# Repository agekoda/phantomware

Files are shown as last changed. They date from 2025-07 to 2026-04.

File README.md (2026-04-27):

<div align="center">

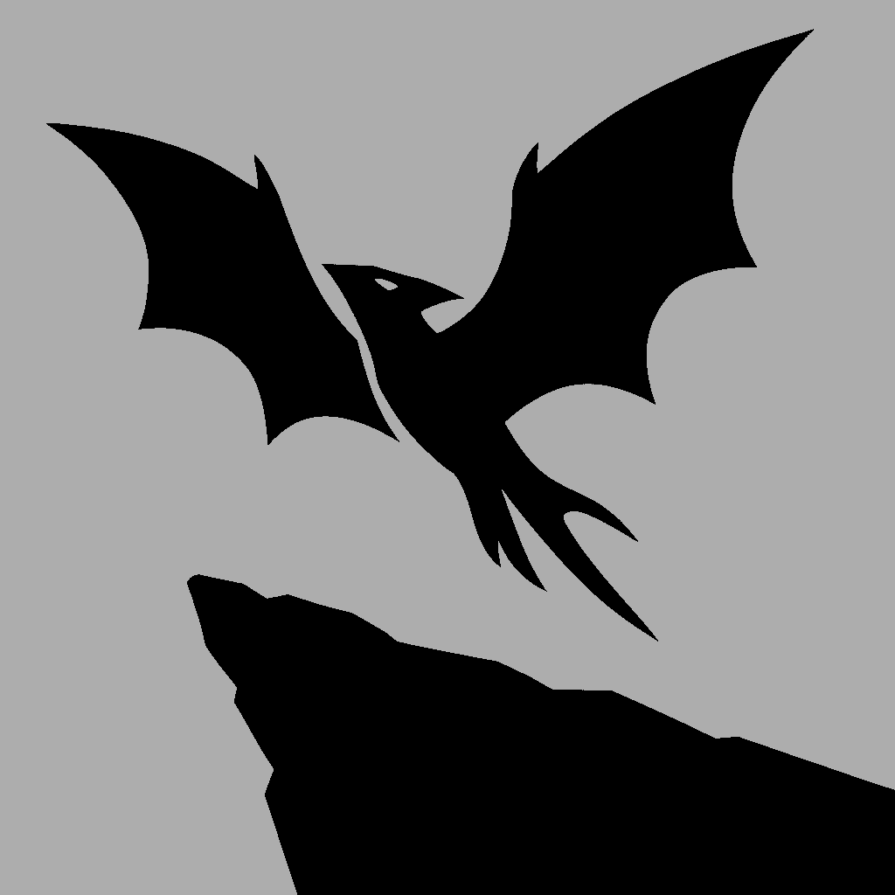
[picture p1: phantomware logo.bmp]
  
  
  <h1> phantomware </h1>
  <p> Compact, powerful ESP32-S3 platform for IR, NFC, sensors, WiFi & more. </p>

<!-- Badges -->





<h4>
  <a href="https://www.tiktok.com/@designedbykoda">
    
  </a>

  <a href="https://www.youtube.com/@zdhd">
    
  </a>

  <a href="https://designedbykoda.com">
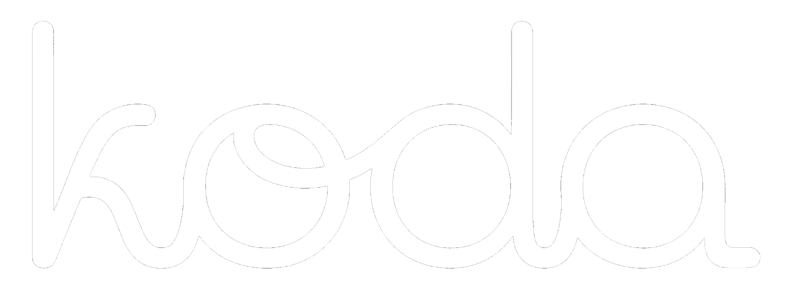
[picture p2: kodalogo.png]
    
  </a>
</h4>
</div>

## 🔥 Overview

Phantomware is a fully custom-built multi-tool device based on the ESP32-S3, designed for wireless analysis, signal interaction, and hardware experimentation.

It combines RF, GPIO, IR, and NFC capabilities into a portable platform featuring a 240×320 TFT display, SD card storage, and a 3000mAh battery system with a full charging circuit, MAX17055 fuel gauge, and built-in overcharge and overcurrent protection.

With 6 navigation buttons and a modular software framework, Phantomware is built for advanced IoT development, prototyping, and hardware exploration.

<div align="center"> 
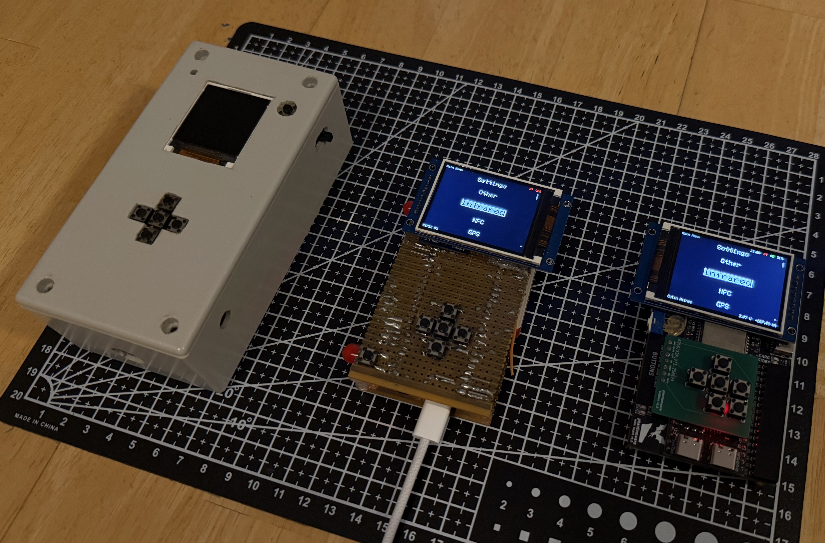
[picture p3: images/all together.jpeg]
  
</div>

<div>&nbsp;</div>

## Phantomware vs. Flipper Zero

| Feature | Phantomware | Flipper Zero |
|---|---|---|
| Microcontroller | ESP32-S3 Dual-core Xtensa LX7 | STM32WB55RG |
| Bluetooth and WiFi? | Bluetooth 5 & WiFi 4 | Bluetooth 5.4 |
| Display | 2" 240x320 TFT LCD | 1.4" 128x64 Monochrome |
| IR Transceiver | 3x VSMY14940 LEDs + TSOP75348WTR | 3x VSMY14940 + TSOP75338TR |
| NFC Support | PN532 via SPI | ST25R3916 |
| Battery & Power Mgmt | 3000mAh LiPo + TP4056 + MAX17055 | 2100mAh + BQ25896 + BQ27220 |
| Expansion Options | Micro SD + 16 GPIOs | Micro SD + 18 GPIOs |
| Target Use Case | Signal analysis, RFID/NFC, IR, tinkering | Sub-GHz, RFID/NFC, IR, utility |
| Open Source? | Open Source & fully customisable | Open Source with limitations |
| Typical Price Point | ~$50 USD | ~$200 USD |

> [!NOTE]
> Information for Flipper Zero is based on publicly available specifications and may vary.

## 🚀 Features

### 🔌 GPIO Toolkit

* PWM signal generator
* Oscilloscope
* Frequency analyser
* Voltmeter
* Resistor calculator
* USB to UART bridge

### 📡 WiFi Tools *(educational use only)*

* Network scan
* Packet monitor
* Spectrum waterfall
* Deauthentication Attack
* Beacon spam
* Evil portal / Captive portal
* Access point hosting
* Connect to AP and host HTML

### 📶 Bluetooth Tools

* BLE scanning
* Device advertisement spam (Apple / Samsung / Windows)

### ⌨️ HID Tools

* BadUSB
* BadBT (Bluetooth HID attacks)

### 💬 Communication

* ESP-NOW messaging
* NRF24-based chat system

### 🧩 Expansion Support

* GPS modules
* PN532 NFC module
* Future GPIO-based add-ons

<!-- nRFBOX V2 -->
## 📸 Versions

<table>
  <tr>
    <td style="text-align: center;">
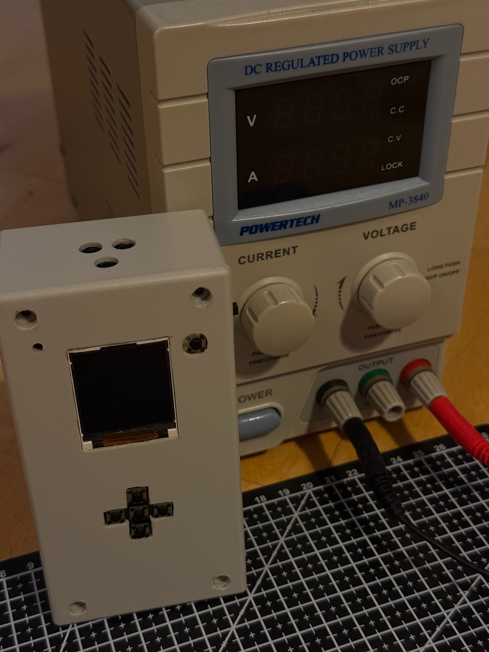
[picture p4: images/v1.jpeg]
phantomware v1
      
      <p style="font-style: italic; font-size: 14px; margin-top: 5px;">v1 prototype based on ESP32</p>
    </td>    
    <td style="text-align: center;">
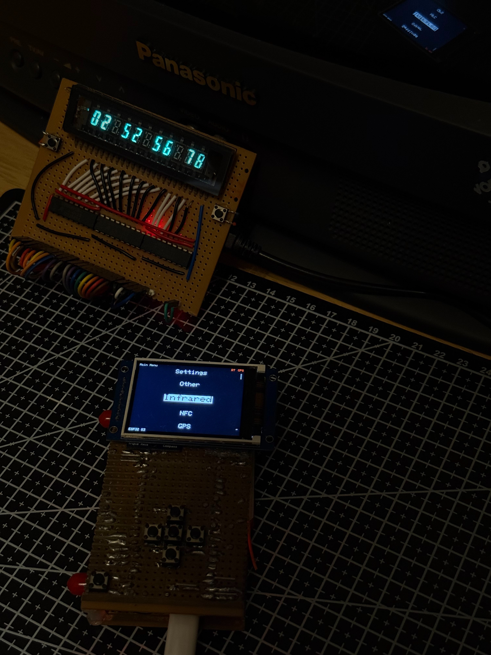
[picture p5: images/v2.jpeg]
phantomware v2
      
      <p style="font-style: italic; font-size: 14px; margin-top: 5px;">v2 based on ESP32-S3</p>
    </td>
    </td>    
    <td style="text-align: center;">
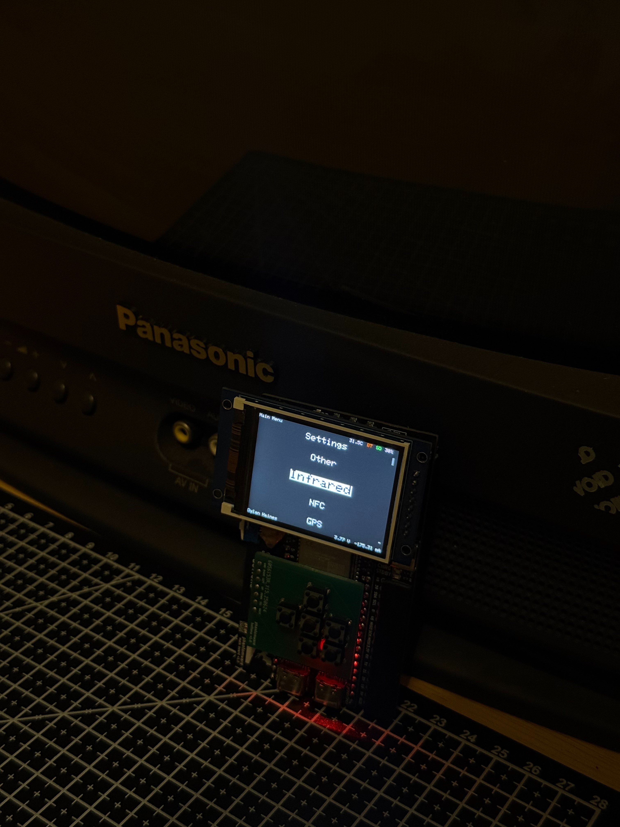
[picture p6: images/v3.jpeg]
phantomware v3
      
      <p style="font-style: italic; font-size: 14px; margin-top: 5px;">v3 based on ESP32-S3 with PCBA and battery</p>
    </td>
  </tr>
</table>

## 🚨 Disclaimer

This project is intended for **educational and research purposes only**.

Do not use this device to interfere with networks, devices, or signals that you do not own or have explicit permission to test. Misuse may violate local laws and regulations.

<!-- License -->
## ⚠️ License

Distributed under the MIT License. See LICENSE.txt for more information.

<!-- Contact -->
## 🤝 Contact

Email - enquiries@designedbykoda.com

Project Link: [https://github.com/agekoda/phantomware](https://github.com/agekoda/phantomware)

<div>&nbsp;</div>

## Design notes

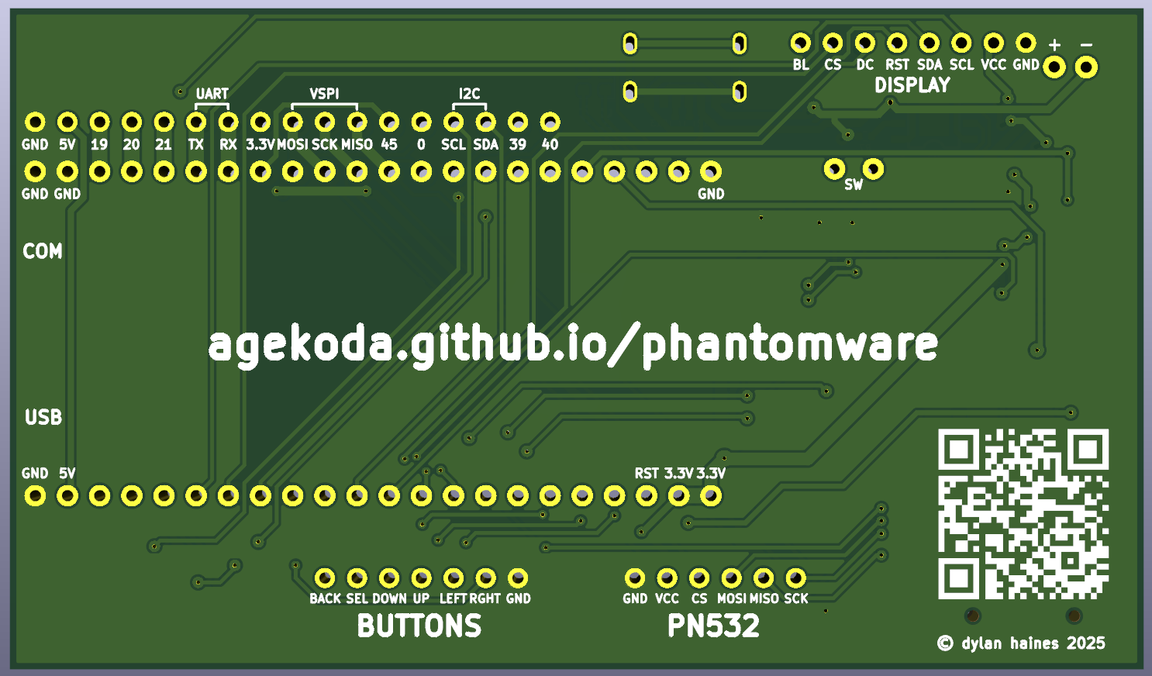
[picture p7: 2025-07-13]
images/back.png

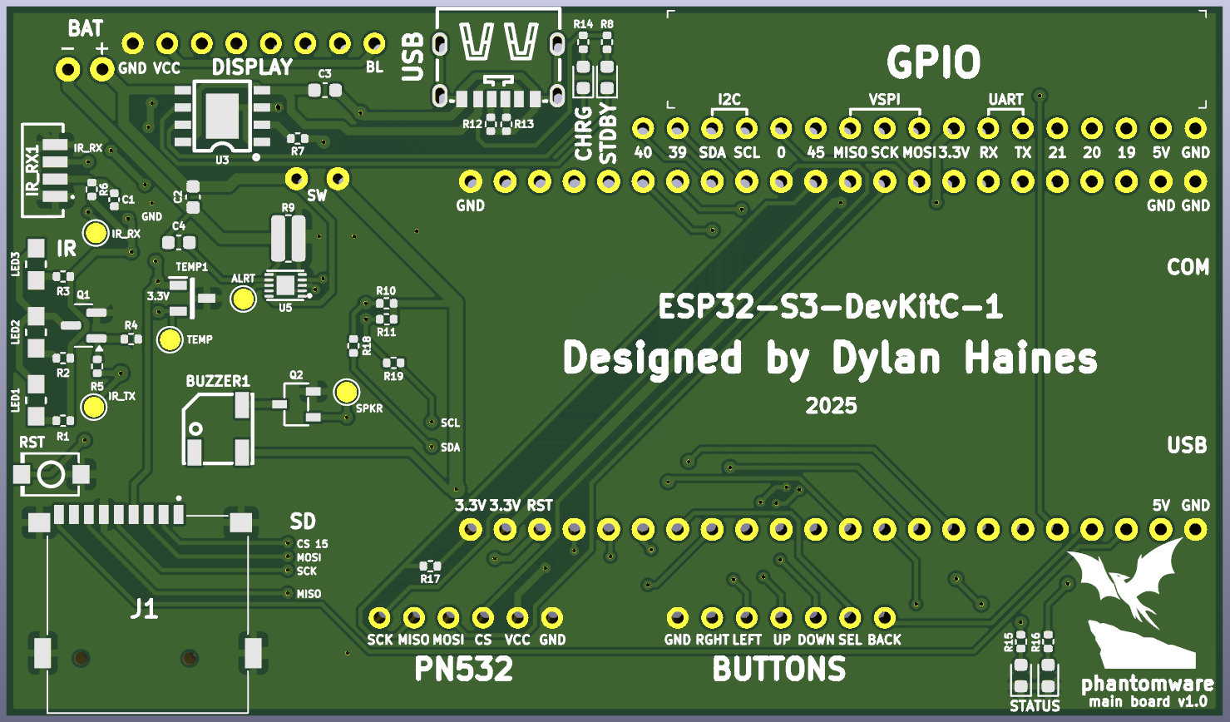
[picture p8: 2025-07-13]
images/front.png

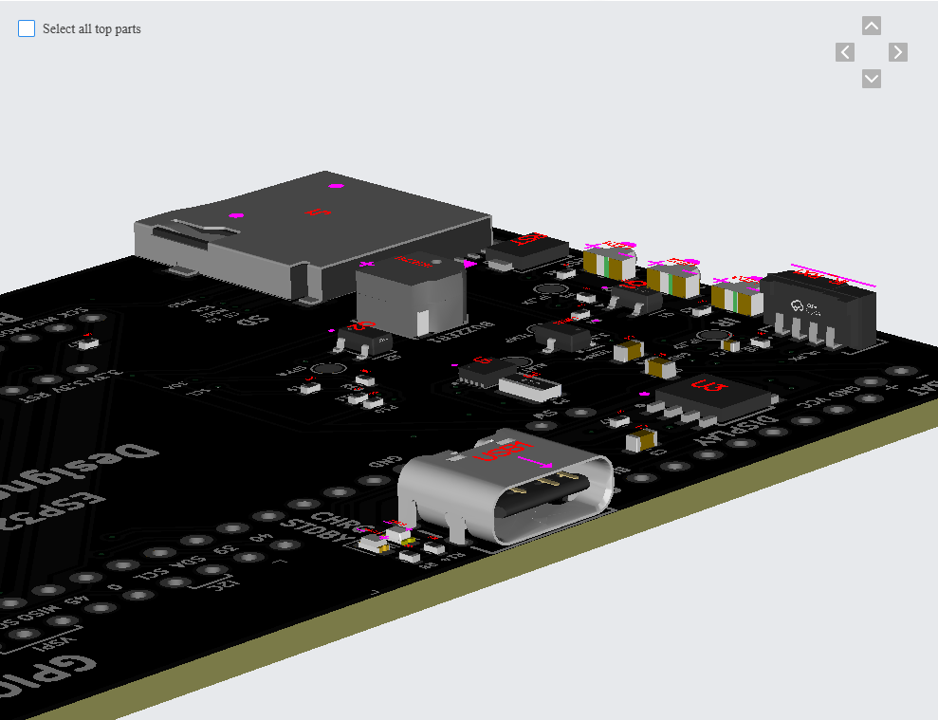
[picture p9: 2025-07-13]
images/3d 3.png

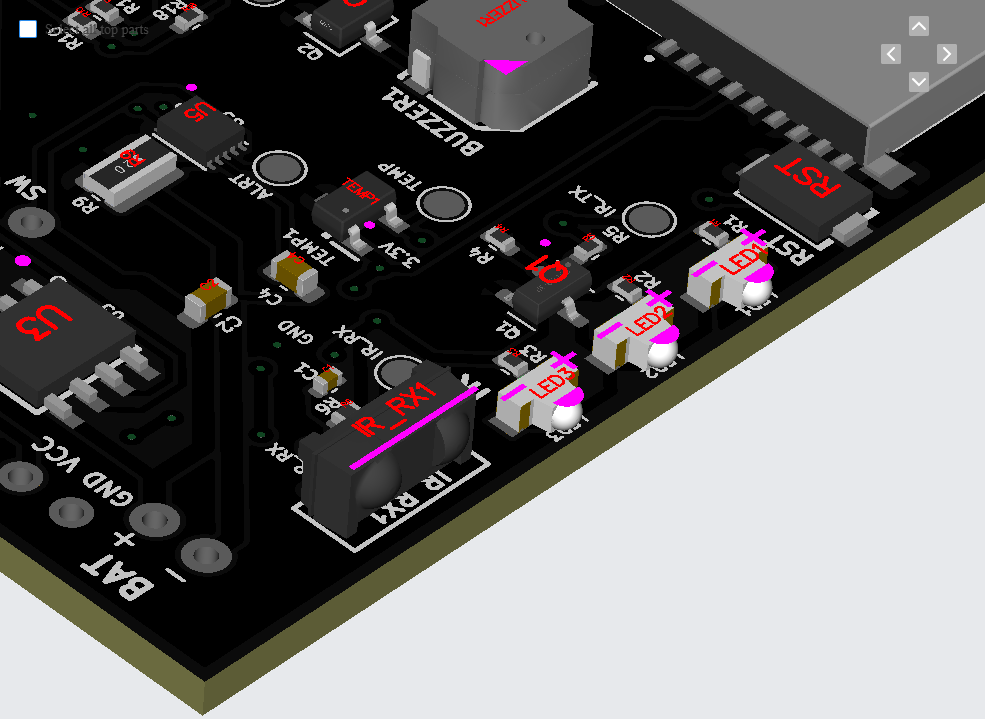
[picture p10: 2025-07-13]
images/3d 1.png

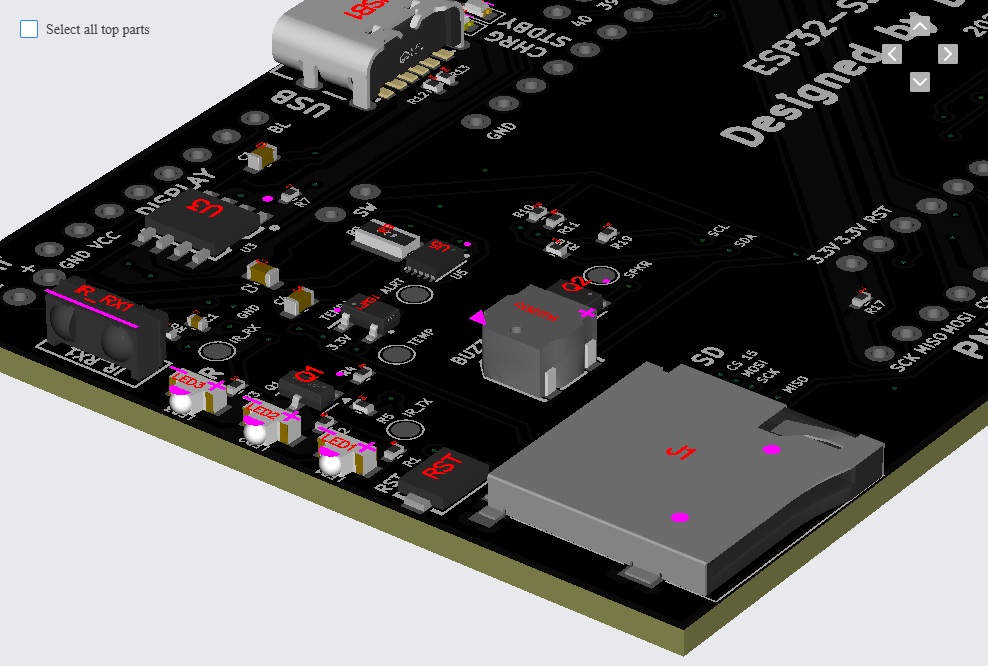
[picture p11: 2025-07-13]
images/3d 2.png

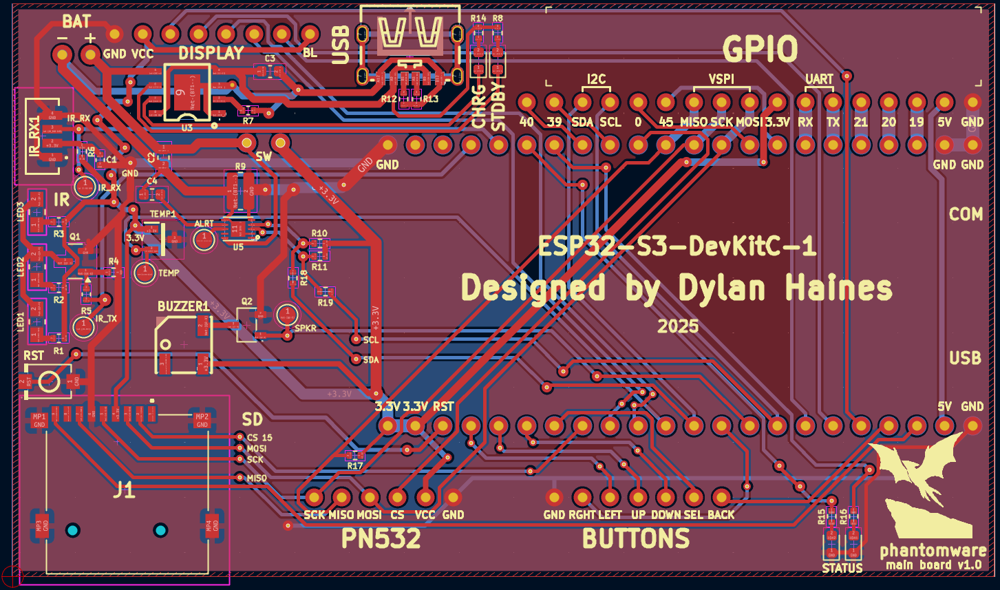
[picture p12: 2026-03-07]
images/pcb.png

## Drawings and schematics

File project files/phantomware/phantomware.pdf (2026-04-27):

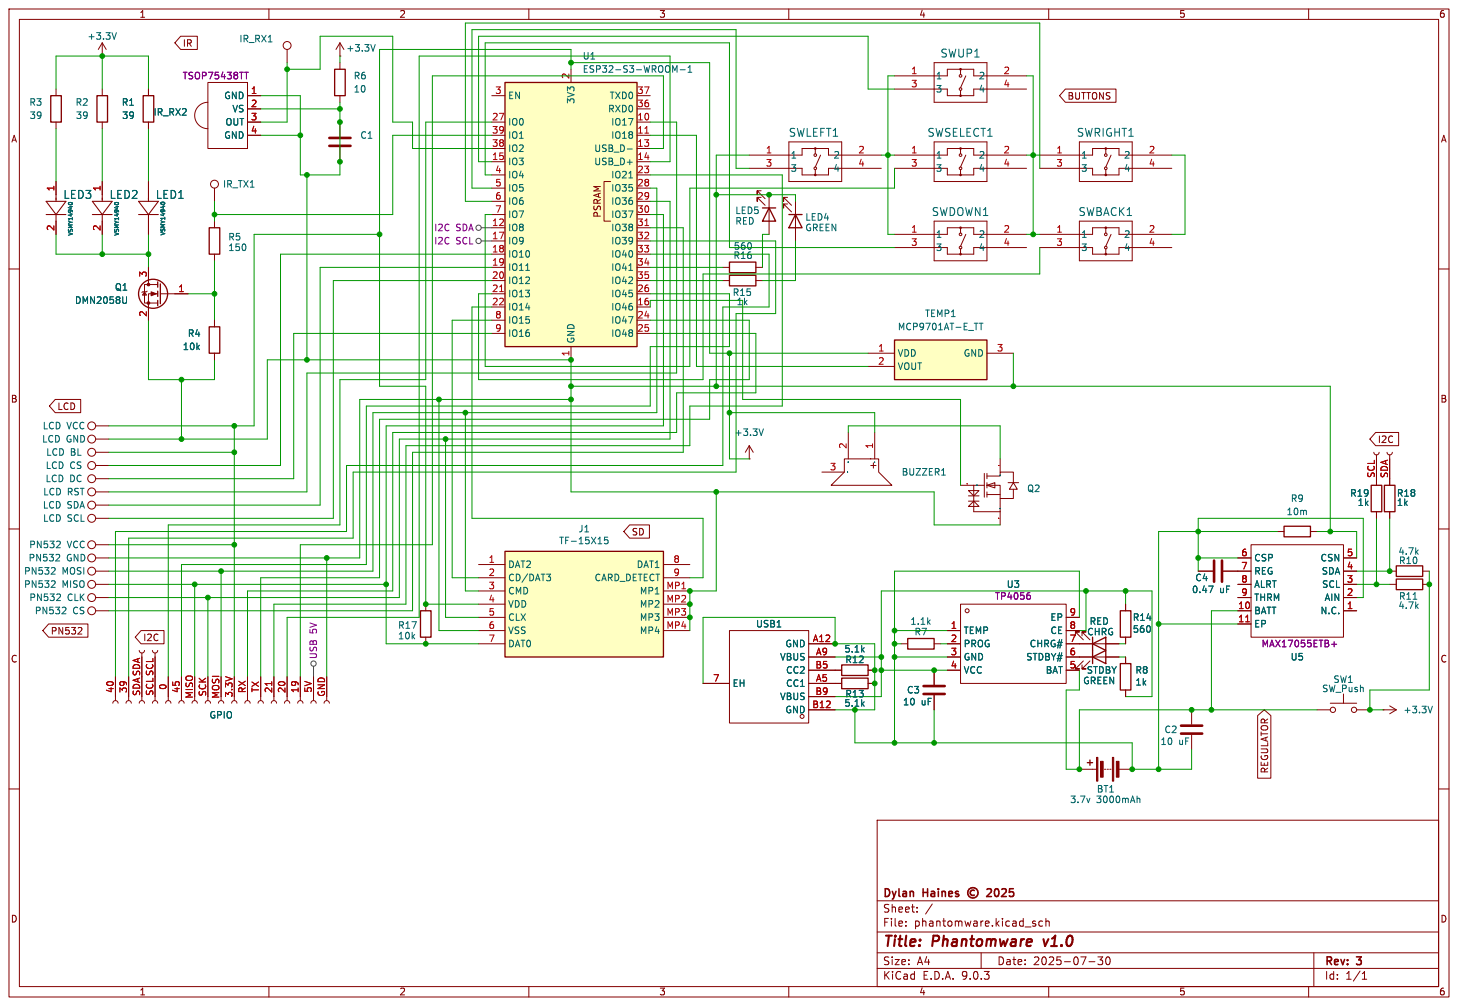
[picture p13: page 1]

IR_RX2TSOP75438TT GND 1 VS 2 OUT 3 GND 4 R1

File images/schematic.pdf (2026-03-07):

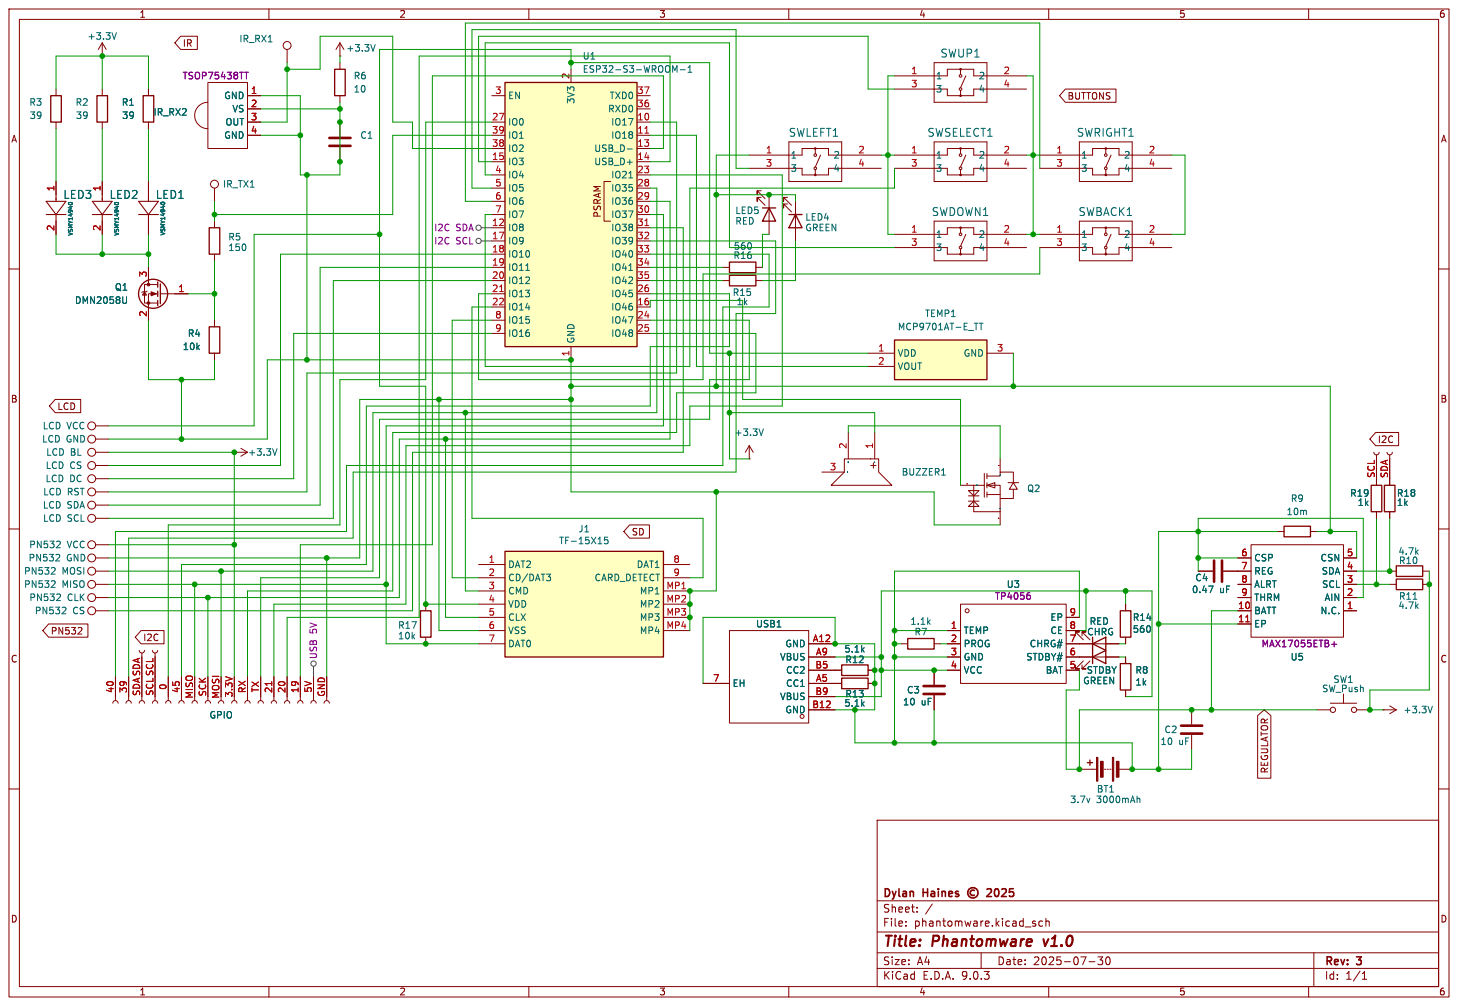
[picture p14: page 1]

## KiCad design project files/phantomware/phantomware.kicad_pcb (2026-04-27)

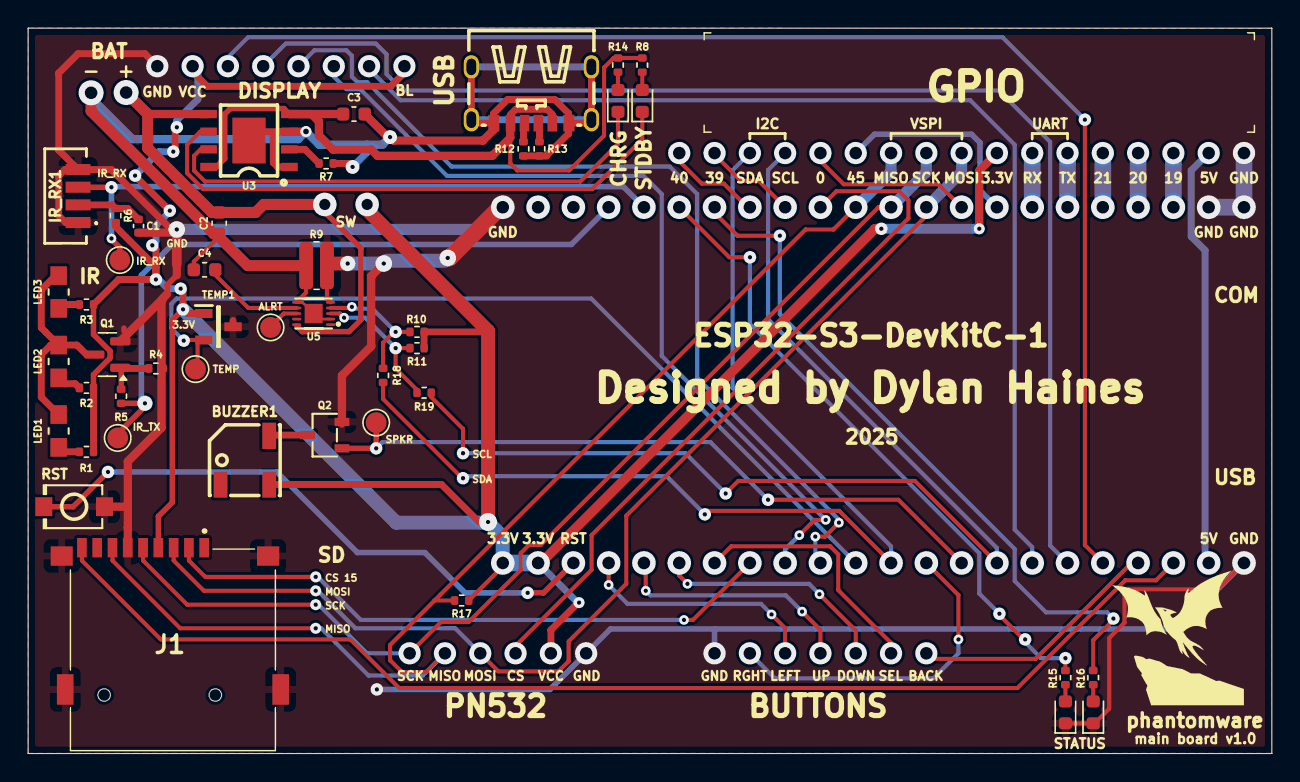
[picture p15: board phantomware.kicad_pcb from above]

Board: 2 copper layers, 89.5 x 52.2 mm, 45 parts (0 on the bottom side), 28 nets.

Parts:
ALRT: TestPoint_Pad_D1.5mm
ALRT#2: TestPoint_Pad_D1.5mm
BUZZER1: 4kHz; smd5x5
C1: 100nF; C_0402_1005Metric
C2, C3: 10 uF; C_0603_1608Metric
C4: 0.47 uF; C_0603_1608Metric
CHRG: RED; LED_0603_1608Metric
IR_RX1: TSOP75338TR
J1: TF-15X15; TF15X15
LED1, LED2, LED3: VSMY14940
LED4: GREEN; LED_0603_1608Metric
LED5: RED; LED_0603_1608Metric
Q1: DMN2058U; SOT-23
Q2: L2N7002KLT1G
R1, R2, R3: 39; R_0402_1005Metric
R4, R17: 10k; R_0402_1005Metric
R5: 130; R_0402_1005Metric
R6: 10; R_0402_1005Metric
R7: 1.1k; R_0402_1005Metric
R8, R15, R18, R19: 1k; R_0402_1005Metric
R9: 10m; R_0612_1632Metric
R10, R11: 4.7k; R_0402_1005Metric
R12, R13: 5.1k; R_0402_1005Metric
R14, R16: 560; R_0402_1005Metric
RST: TS-1088-AR02016
STDBY: GREEN; LED_0603_1608Metric
TEMP: TestPoint_Pad_D1.5mm
TEMP1: MCP9701AT-E_TT; SOT95P237X112-3N
TEMP#2, TEMP#3: TestPoint_Pad_D1.5mm
U3: TP4056
U5: MAX17055ETB+
USB1: TYPE-C-SMD_TYPE-C-6P_5

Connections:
+3.3V: BUZZER1.1, C1.1, IR_RX1.2 (VS), J1.4 (VDD), R1.1, R2.1, R3.1, R6.1, R6.2, R10.1, R11.1, R17.1, TEMP1.1 (VDD)
GND: C1.2, IR_RX1.1 (GND), IR_RX1.4 (GND), J1.6 (VSS), J1.MP1, J1.MP2, J1.MP3, J1.MP4, LED4.1 (K), LED5.1 (K), Q1.2 (S), Q2.2 (S), R4.2, R9.2, RST.1, TEMP1.3 (GND), U5.5 (CSN)
IO41: LED5.2 (A), R16.1, R16.2
IO42: LED4.2 (A), R15.1, R15.2
unnamed: C2.1, U3.5 (BAT), U5.10 (BATT)
unnamed: C2.2, C3.2, C4.1, R7.2, R9.1, R12.1, R13.2, U3.1 (TEMP), U3.3 (GND), U3.9 (EP), U5.2 (AIN), U5.6 (CSP), U5.11 (EP), USB1.7 (EH), USB1.A12 (GND), USB1.B12 (GND)
unnamed: IR_RX1.3 (OUT), TEMP#3.1
unnamed: J1.7 (DAT0), R17.2
unnamed: LED1.1, R1.2
unnamed: LED3.1, R3.2
unnamed: LED2.1, R2.2
unnamed: CHRG.2 (A), R14.1
unnamed: CHRG.1 (K), U3.7 (CHRG#)
unnamed: R8.2, STDBY.2 (A)
unnamed: STDBY.1 (K), U3.6 (STDBY#)
unnamed: LED1.2, LED2.2, LED3.2, Q1.3 (D)
unnamed: Q1.1 (G), R4.1, R5.2
unnamed: BUZZER1.2, Q2.3 (D)
unnamed: ALRT.1, Q2.1 (G)
unnamed: TEMP1.2 (VOUT), TEMP#2.1
unnamed: R5.1, TEMP.1
unnamed: C3.1, R8.1, R14.2, U3.4 (VCC), U3.8 (CE), USB1.A9 (VBUS), USB1.B9 (VBUS)
unnamed: R7.1, U3.2 (PROG)
unnamed: C4.2, U5.7 (REG)
unnamed: R11.2, R19.1, R19.2, U5.3 (SCL)
unnamed: R10.2, R18.1, R18.2, U5.4 (SDA)
unnamed: R13.1, USB1.A5 (CC1)
unnamed: R12.2, USB1.B5 (CC2)

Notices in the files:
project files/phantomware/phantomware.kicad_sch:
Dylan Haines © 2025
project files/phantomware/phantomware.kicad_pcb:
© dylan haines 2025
